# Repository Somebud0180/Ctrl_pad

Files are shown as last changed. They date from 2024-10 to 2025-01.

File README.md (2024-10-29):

Ctrl_pad_img

# Ctrl_pad
A 3x3 macropad with an encoder and OLED display. Powered by [QMK](https://github.com/qmk/qmk_firmware).

### Modifications
PCB in black, case is all white, plate in transparent acrylic

### BOM
| Part | Amount |
| :----- | :----: |
| PCB | 1 |
| Acrylic Plate Piece | 1 |
| 3D Printed Case Pieces | 3 |
| M2X5 Screw | 1 |
| M3X12 Screws | 2 |
| M3X6 Screws | 2 |
| M2 Heat Set Inserts | 1 |
| M3 Heat Set Inserts | 4 |
| EC11 Encoder | 1 |
| 0.96" SSD1306 OLED Display | 1 |
| Gateron Milky Yellows | 8 |
| Mill-Max 0305s | 16* |
| 4.7K Through-hole Resistors| 2 |
| Through-hole 1N4148 Diodes | 9 |

*<sup> assuming one per socket

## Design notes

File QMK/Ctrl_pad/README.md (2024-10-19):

# ctrl_pad

ctrl_pad

*A 3x3 macropad with an OLED display*

* Keyboard Maintainer: [Ethan John Lagera](https://github.com/Somebud0180)
* Hardware Supported: *The PCBs, controllers supported*
* Hardware Availability: *Links to where you can find this hardware*

Make example for this keyboard (after setting up your build environment):

    make ctrl_pad:default

Flashing example for this keyboard:

    make ctrl_pad:default:flash

See the [build environment setup](https://docs.qmk.fm/#/getting_started_build_tools) and the [make instructions](https://docs.qmk.fm/#/getting_started_make_guide) for more information. Brand new to QMK? Start with our [Complete Newbs Guide](https://docs.qmk.fm/#/newbs).

## Bootloader

Enter the bootloader in 3 ways:

* **Bootmagic reset**: Hold down the key at (0,0) in the matrix (usually the top left key or Escape) and plug in the keyboard
* **Physical reset button**: Briefly press the button on the back of the PCB - some may have pads you must short instead
* **Keycode in layout**: Press the key mapped to `QK_BOOT` if it is available

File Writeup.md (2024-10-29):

# Ctrl_pad **(The Writeup/Blurbs)**
A macropad with 5 keys, an encoder and an 0.96" OLED display. It runs on QMK, hopes and dreams.

Ctrl_pad_img

It looks (approximately) like this. 

### Inspirations
The PCB is plain old standard for the most part, a rounded rectangular PCB because everyting is rounded these days and a few designs. The main design (attempt) takes from macOS and its shortcut symbols. The case follows on the PCB and so on. Why white? I took a look at black and decided, this ain't it.

### Challenges
Having done OnBoard, PCB design was (supposed to be) a lot better than my first time. Moving from EasyEDA to KiCAD was a bit wonky, but positioning and making parts work was the bulk of the challenge. Examples are, “Do I really need this resistor", “Did I wire this correctly" and "Is this spot okay". Making the case, it was mostly held back on what I could think. I did spend some chunk of my time on the specifics like holes, clearance, positioning and making sure this was possible to print. Firmware was also wonky. Most of it was easy until it wasn’t. Enabling LTO had a mini hold up, but with the abundance of documentation and a little help (the help being AI), it became a lot more manageable.

### Fun(?) Fact
- The name was supposed to be iCtrl, I decided maybe it isn't that kewl.
- I redid the switches, diodes and wiring about three times, maybe more.
- To _stand_ out, I made the biggest gamble on hoping I can pull off the removable **stand** (Pun not intended).
- Speaking of stands, I probably had 3 or more designs on how to attatch it.
- I took a break by rendering the model in Fusion, I also did some manufacturing simulation because I wanted to.
- I don't know C, I did not make the OLED code.

### What I learned
More PCB stuff, how to make a keyboard, how to 3D model, how to use QMK, KiCad, Fusion and a few more. I also learned that I have time as long as I want to do something enough.

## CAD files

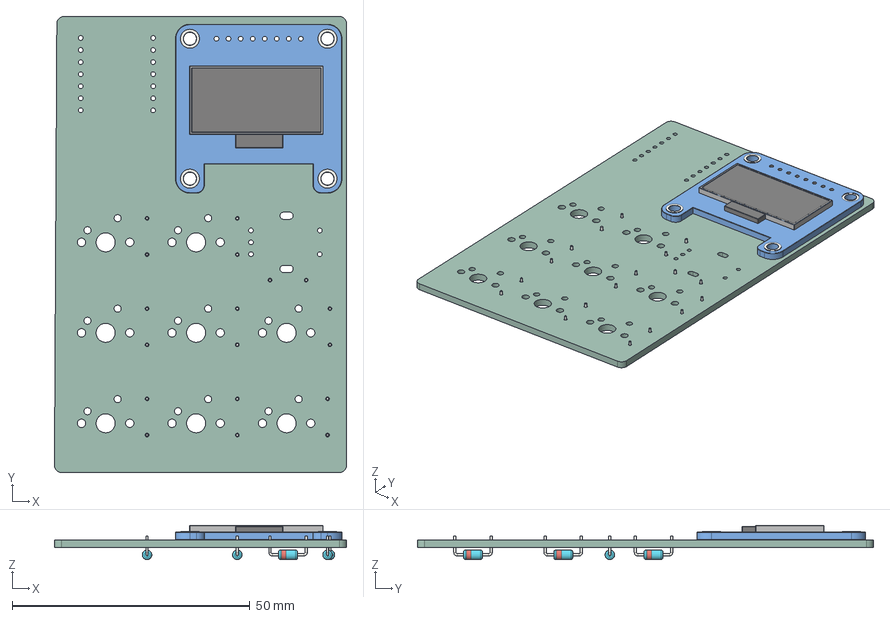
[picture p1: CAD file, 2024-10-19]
PCB/PCB Step/Ctrl_pad PCB (0).step
61.5 x 96.0 x 7.21 mm
Adafruit_SSD1306
D_DO-35_SOD27_P7.62mm_Horizontal x 9
iCtrl_PCB

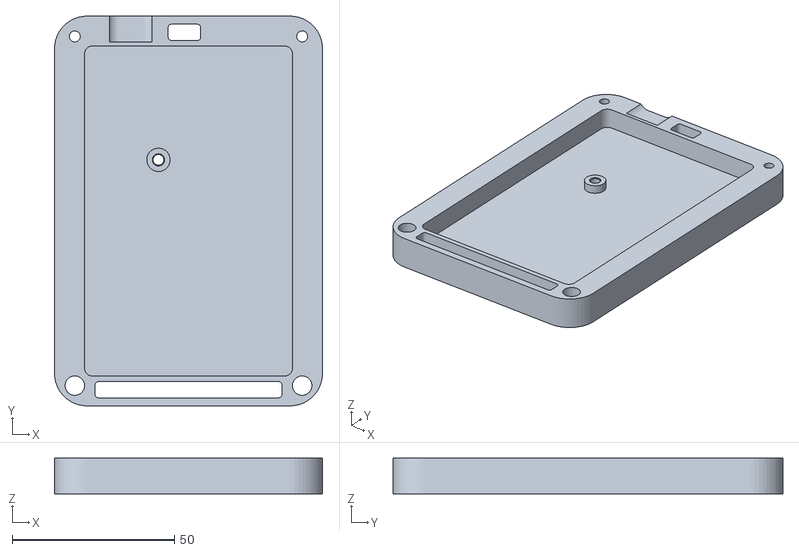
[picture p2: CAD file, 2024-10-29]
Production/case/Ctrl_pad Body.stl
82.5 x 120.0 x 11.0

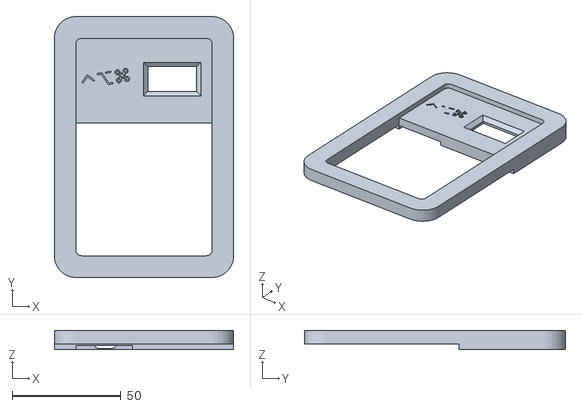
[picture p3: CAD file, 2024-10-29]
Production/case/Ctrl_pad Top.stl
82.5 x 120.0 x 8.96

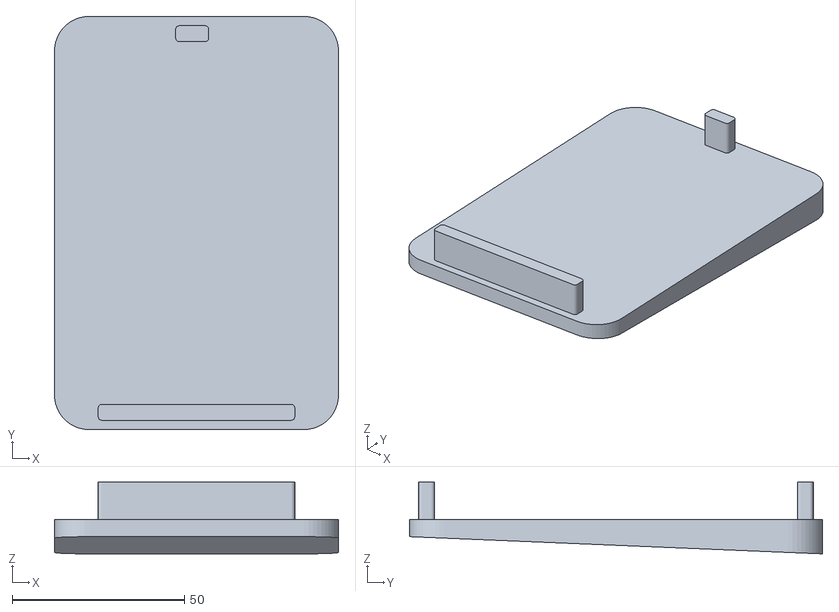
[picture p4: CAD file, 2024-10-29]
Production/case/Ctrl_pad Stand.stl
82.5 x 120.0 x 20.8

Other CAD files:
PCB/PCB Step/Ctrl_pad PCB (1).step
Production/case/Ctrl_pad Plate.dxf

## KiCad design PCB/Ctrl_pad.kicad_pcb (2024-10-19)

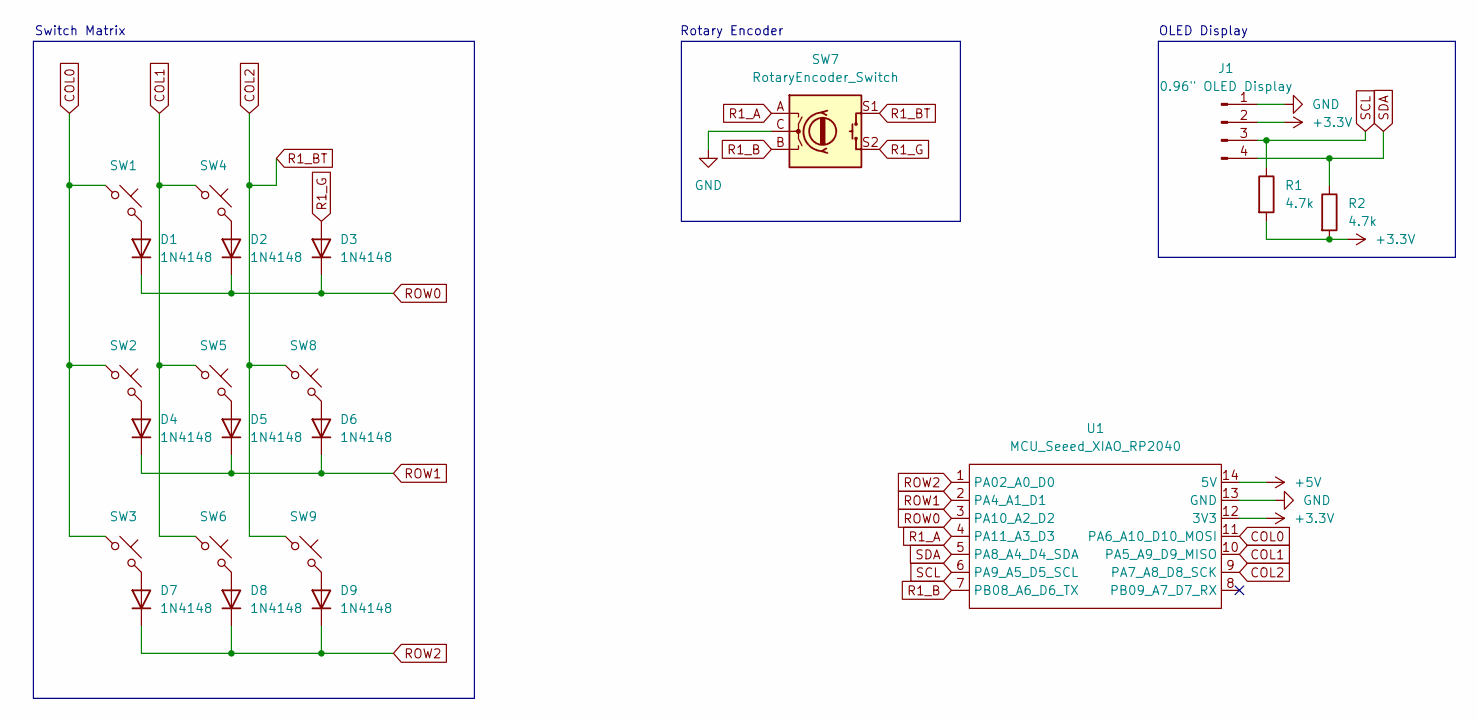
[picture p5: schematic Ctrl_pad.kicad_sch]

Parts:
D1, D2, D3, D4, D5, D6, D7, D8, D9: 1N4148; D_DO-35_SOD27_P7.62mm_Horizontal
J1: 0.96" OLED Display; Adafruit_SSD1306
R1, R2: 4.7k; R_Axial_DIN0204_L3.6mm_D1.6mm_P5.08mm_Horizontal
SW1, SW2, SW3, SW4, SW5, SW6, SW8, SW9: MX; MX_PCB_1.00u
SW7: RotaryEncoder_Switch; Encoder_EC11_MX
U1: MCU_Seeed_XIAO_RP2040; Seeed_XIAO_RP2040

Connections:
+3.3V: J1.2, R1.2, R2.2, U1.12 (3V3)
+5V: U1.14 (5V)
COL0: SW1.1, SW2.1, SW3.1, U1.11 (PA6_A10_D10_MOSI)
COL1: SW4.1, SW5.1, SW6.1, U1.10 (PA5_A9_D9_MISO)
COL2: SW7.S1, SW8.1, SW9.1, U1.9 (PA7_A8_D8_SCK)
GND: J1.1, SW7.C, U1.13 (GND)
unnamed: D1.2 (A), SW1.2
unnamed: D2.2 (A), SW4.2
unnamed: D4.2 (A), SW2.2
unnamed: D5.2 (A), SW5.2
unnamed: D6.2 (A), SW8.2
unnamed: D7.2 (A), SW3.2
unnamed: D8.2 (A), SW6.2
unnamed: D9.2 (A), SW9.2
R1_A: SW7.A, U1.4 (PA11_A3_D3)
R1_B: SW7.B, U1.7 (PB08_A6_D6_TX)
R1_G: D3.2 (A), SW7.S2
ROW0: D1.1 (K), D2.1 (K), D3.1 (K), U1.3 (PA10_A2_D2)
ROW1: D4.1 (K), D5.1 (K), D6.1 (K), U1.2 (PA4_A1_D1)
ROW2: D7.1 (K), D8.1 (K), D9.1 (K), U1.1 (PA02_A0_D0)
SCL: J1.3, R1.1, U1.6 (PA9_A5_D5_SCL)
SDA: J1.4, R2.1, U1.5 (PA8_A4_D4_SDA)

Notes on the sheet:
Rotary Encoder
OLED Display
Switch Matrix

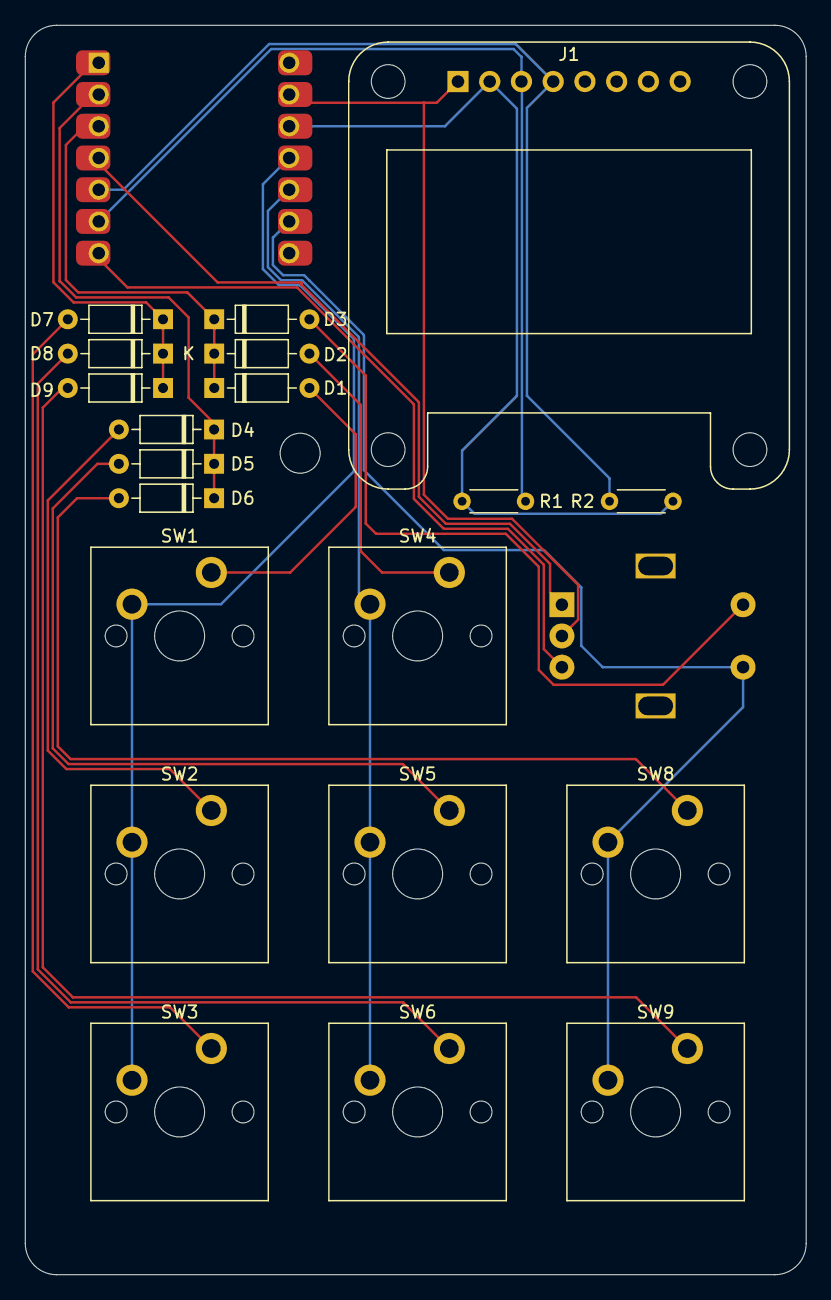
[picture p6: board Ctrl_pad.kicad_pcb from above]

Board: 2 copper layers, 62.5 x 100.0 mm, 22 parts (0 on the bottom side), 21 nets.

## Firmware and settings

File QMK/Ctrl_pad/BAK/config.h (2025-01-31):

#define LAYER_STATE_8BIT

#define ENCODER_A_PINS { GP29 }
#define ENCODER_B_PINS { GP0 }

#define I2C_DRIVER I2CD1
#define I2C1_SDA_PIN GP6
#define I2C1_SCL_PIN GP7

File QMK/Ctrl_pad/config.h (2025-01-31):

#define RP2040_BOOTLOADER_DOUBLE_TAP_RESET
#define RP2040_BOOTLOADER_DOUBLE_TAP_RESET_TIMEOUT 200U
#define RP2040_BOOTLOADER_DOUBLE_TAP_RESET_LED GP17 
#define LAYER_STATE_8BIT

#define OLED_DISPLAY_128X64
#define OLED_TIMEOUT 10000
#define OLED_BRIGHTNESS 128
#define I2C_DRIVER I2CD1
#define I2C1_SDA_PIN GP6
#define I2C1_SCL_PIN GP7

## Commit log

2024-10-19 Added libraries and assets, updated files
    [Case Body.stp, Case Stand.stp, Case Top.stp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]
2024-10-19 Updated Design
    [Ctrl_pad Body.stl, Ctrl_pad Plate.dxf, Ctrl_pad Stand.stl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]
2024-10-19 Delete Case directory
    Replaced with CAD and Production
    [Case Body.stp, Case Stand.stp, Case Top.stp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]
2024-10-29 Update Case and 3D Model
    Updated the case to properly fit the MCU on a pin.
    [Ctrl_pad Body.stl, Ctrl_pad Plate.dxf, Ctrl_pad Stand.stl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]
2025-01-31 Update firmware
    Functionality Update:
    Made some changes to the config to enable the OLED, change the brightness and the timeout,
    Fixed the orientation of the keys and also changed some of the key binds (added a copy, cut, paste to the Ctrl layer),
    Fixed (?) the OLED function a bit (Kinda got fast forwarded since I didn't get to commit that part),
    Fixed rotary encoder (returns false instead to override the encoder default keybind),
    Added glyph for volume and brightness control animation (Made with PixelRat!),
    Added a animation function to actually animate the glyphs,
    And other stuff I might've forgotten.
    [config.h, keymap.c]
